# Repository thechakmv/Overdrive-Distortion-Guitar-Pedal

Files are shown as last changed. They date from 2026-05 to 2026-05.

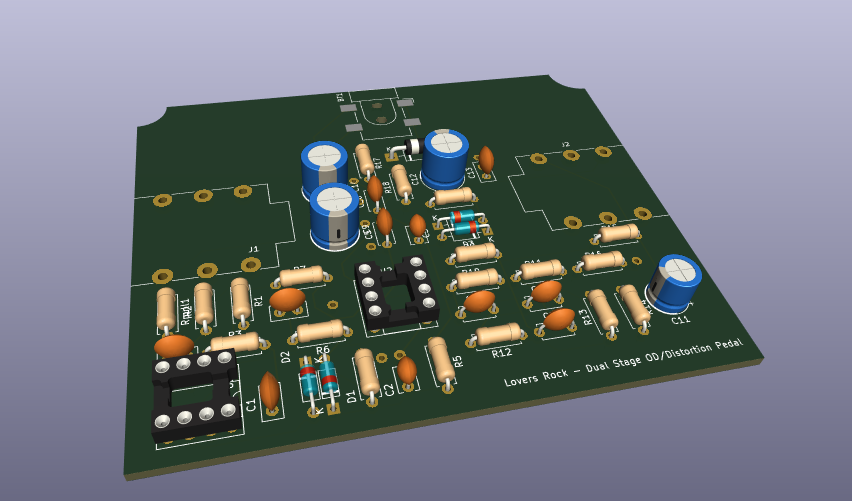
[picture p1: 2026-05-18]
images/pcb_3d.png

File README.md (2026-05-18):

# Dual-Stage Overdrive & Distortion Guitar Pedal

I created analog guitar effects pedal with two independent, switchable gain stages featuring deliberately opposite midrange voicings to achieve classic Thrash metal rhythm and lead tones: a soft-clipping overdrive with a **mid-boost** (+6 dB at 800 Hz) and a hard-clipping distortion with a **mid-scoop** (−6 to −10 dB across 400–800 Hz). The Pedal features a single-knob passive tone control, and volume control as well. Each stage has true-bypass switching, so the two can run independently or be cascaded for stacked high-gain tones.

## Highlights

- Designed and simulated in LTSpice; verified Bode plots, transient behavior, and FFT spectrum on hardware
- Two-stage analog signal chain built around TL072 JFET-input op-amps
- True-bypass per stage via 3PDT footswitches; both stages engage simultaneously for cascaded gain
- Passive Twin-T notch filter for the distortion mid-scoop voicing
- Single 9 V DC supply, ~30 mA total current draw
- PCB layout in KiCad with attention to signal integrity, star-ground topology, and inter-stage isolation

## Signal Flow

```
                                                         
 Guitar ─> Input ─┬─> OD Stage ──┬─> Distortion ──┬─> Tone ─> Volume ─> Output ─> Amp
          Buffer  │   (soft clip,│   (hard clip + │  (LPF)    (audio)   Buffer
          (TL072) │   mid-boost) │   Twin-T scoop)│
                  │              │                │
                  ▼              ▼                ▼
                SW1 3PDT        SW2 3PDT       Always
                true bypass     true bypass    in signal path
```

When both footswitches are engaged, the OD output feeds the distortion stage input, producing cascaded high-gain saturation. Each stage can also run alone for cleaner crunch or for chunkier rhythm tones.

## Design Specifications

| Parameter | Value |
|---|---|
| Supply | 9 V DC, center-negative, ~30 mA |
| Frequency response (clean path) | Flat ±0.5 dB across 20 Hz – 20 kHz |
| OD voicing | +6 dB peak at 800 Hz; corners at 720 Hz and ~6 kHz |
| OD gain range | 0 dB to +41 dB |
| OD clipping | Soft, symmetric, ±0.6 V (1N4148 anti-parallel in feedback) |
| Distortion voicing | −6 to −10 dB notch centered at ~700 Hz |
| Distortion gain range | +14 dB to +54 dB |
| Distortion clipping | Hard, symmetric, ±0.6 V (1N4148 to Vref) |

## Design Philosophy

Where most pedals use a single clipping topology, this design uses two intentionally distinct stages whose characters complement each other when cascaded.

The **overdrive stage** is a Tube Screamer-derived non-inverting topology with silicon diodes inside the feedback loop. The feedback RC network forms a band-pass response: lows roll off below 720 Hz and highs roll off above ~6 kHz at maximum gain. Inside the band the gradual diode conduction produces soft clipping that preserves the dry signal underneath the saturation, giving the characteristic transparent overdrive sound.

The **distortion stage** uses an inverting topology with diodes clamping the op-amp output directly to the Vref node. This produces hard, square-wave clipping rich in odd harmonics. The clipped signal then feeds a passive Twin-T notch filter centered near 700 Hz, carving out the boxy midrange while leaving low and high content intact — the classic scooped-mid metal voicing.

The two stages are independently switchable: OD alone for crunch, distortion alone for chunky rhythm work, or both stacked for full-saturation lead tones.

## Repository Structure

```
├── ltspice/
│   ├── od_stage.asc
│   ├── distortion_stage.asc
│   └── Overdrive_Distortion_Schematic.asc              
├── kicad/
│   ├── pedal.kicad_pro             Project file
│   ├── pedal.kicad_sch             Schematic
│   ├── pedal.kicad_pcb             Board layout
│   └── gerbers/                    Fabrication output (zipped Gerbers + drill)
└── images/
    ├── frequency_response.png      Measured Bode plots
    ├── pcb_schematic.png          Spectrum analyzer captures
    └── pcb_3d.png                  Oscilloscope captures
```

## Tools

**Software:** LTSpice, KiCad 7

**Test equipment:** oscilloscope (FFT capable), signal generator, multimeter, soldering iron

## Build Process

1. **Simulate.** Run AC and transient analyses in LTSpice for each stage. Verify gain curves, clipping shape, and Vref stability under load. Use `.step` to sweep gain pot values and see the response variation across the control range.

2. **Breadboard.** Build stage-by-stage with bench power. Validate against simulation results with scope and FFT. This is the stage to tune by ear — swap diodes (Si vs. LED vs. asymmetric), tweak the scoop center frequency, dial in the gain ranges.

3. **PCB.** Re-capture the validated schematic in KiCad, assign through-hole footprints, lay out the board with the panel-component headers anchored to enclosure positions. Generate Gerbers and fabricate via JLCPCB or OSH Park.

**In Progress:**
1. **Assemble.** Populate the PCB; wire off-board panel components (pots, footswitches, jacks); mount in enclosure.

2. **Verify.** Measure assembled pedal's frequency response and FFT; compare against simulation predictions.

## Testing & Verification

The hardware was validated against simulation using:

**Bode plots:** swept sine across 20 Hz – 20 kHz, output captured on oscilloscope, magnitude plotted in dB. Measured curve matches LTSpice AC analysis within ±2 dB across the band.

**FFT analysis:** 1 kHz sine input at each stage's clipping threshold, output FFT'd to verify harmonic content. The OD stage shows soft-clip characteristic harmonic roll-off; the distortion stage shows hard-clip odd-harmonic series with a clear notch at ~700 Hz after the Twin-T.

## Design Issues Encountered (and Fixed)

Three non-obvious problems came up during simulation and breadboarding that are worth documenting:

**Vref instability under heavy distortion.** The hard-clipping diodes were pumping asymmetric current pulses into the unbuffered Vref node, dragging it from 4.5 V down toward 1 V during sustained clipping. Fixed by adding a 1 kΩ series resistor between the distortion op-amp's output and the diode pair, limiting peak diode current and preserving Vref bias integrity.

**High-frequency oscillation at high gain.** The TL072 stages were prone to oscillation when driving capacitive loads (cable runs, coupling caps). Fixed by adding a 470 Ω series isolation resistor between each op-amp output and its capacitive load, with feedback taken before the resistor.

**Switch-engage pop.** Resolved by adding 1 MΩ pull-down resistors on both sides of every coupling cap that interfaces with a footswitch, ensuring no DC charge accumulates on the disconnected side of the cap during bypass.

## Skills Demonstrated

- Analog circuit design with op-amps (inverting, non-inverting, follower topologies)
- Frequency-response shaping via reactive feedback networks
- Soft-clipping vs. hard-clipping topology selection and harmonic analysis
- Single-supply audio biasing: Vref generation, AC coupling, bypass strategy
- Passive filter design (Twin-T notch with derivation of component ratios)
- SPICE simulation: AC sweep, transient analysis, FFT, parametric stepping
- PCB layout for analog audio: ground topology, decoupling, inter-stage isolation
- Hardware validation against simulation with scope and spectrum analyzer

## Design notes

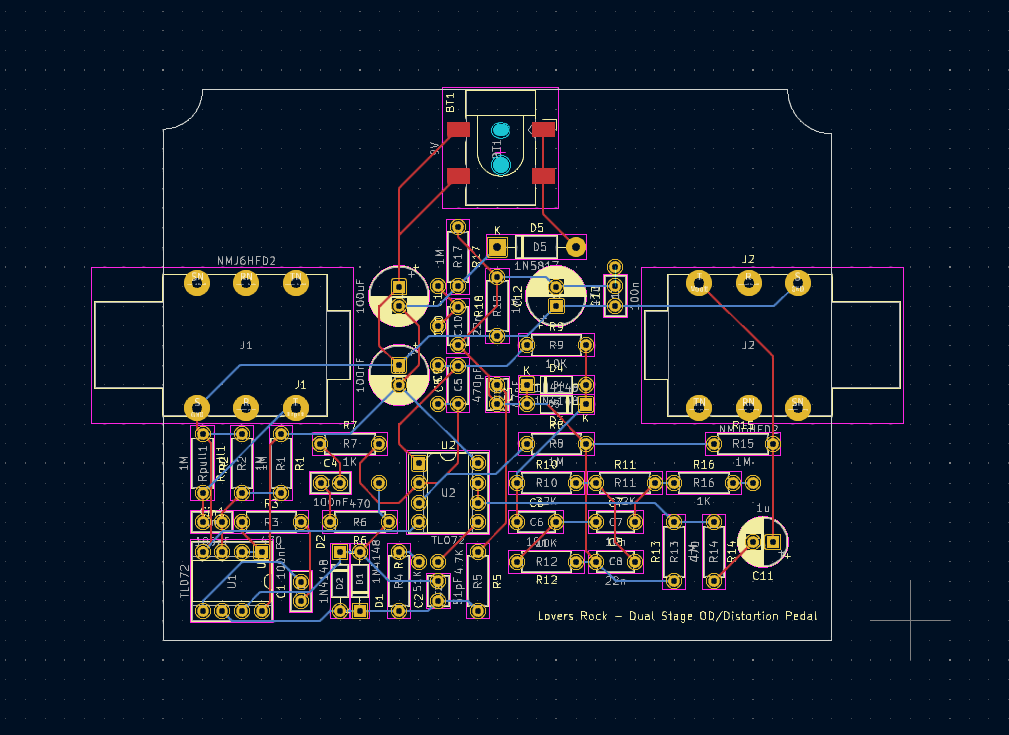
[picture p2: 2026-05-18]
images/pcb_schematic.png

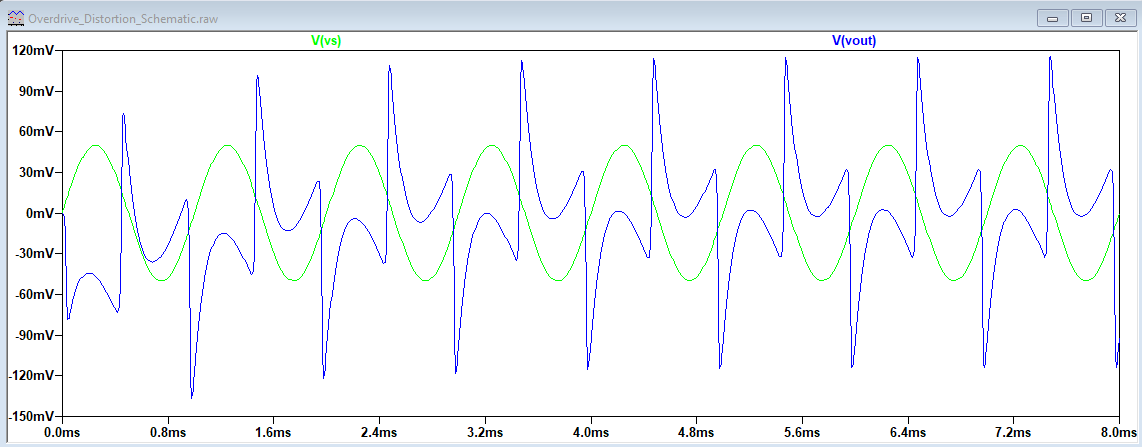
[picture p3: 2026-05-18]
images/transient.png

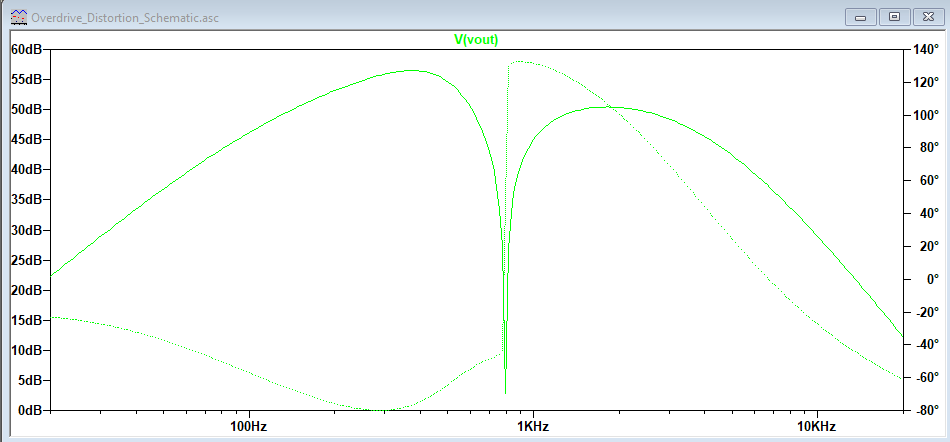
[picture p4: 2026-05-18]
images/frequency_response.png

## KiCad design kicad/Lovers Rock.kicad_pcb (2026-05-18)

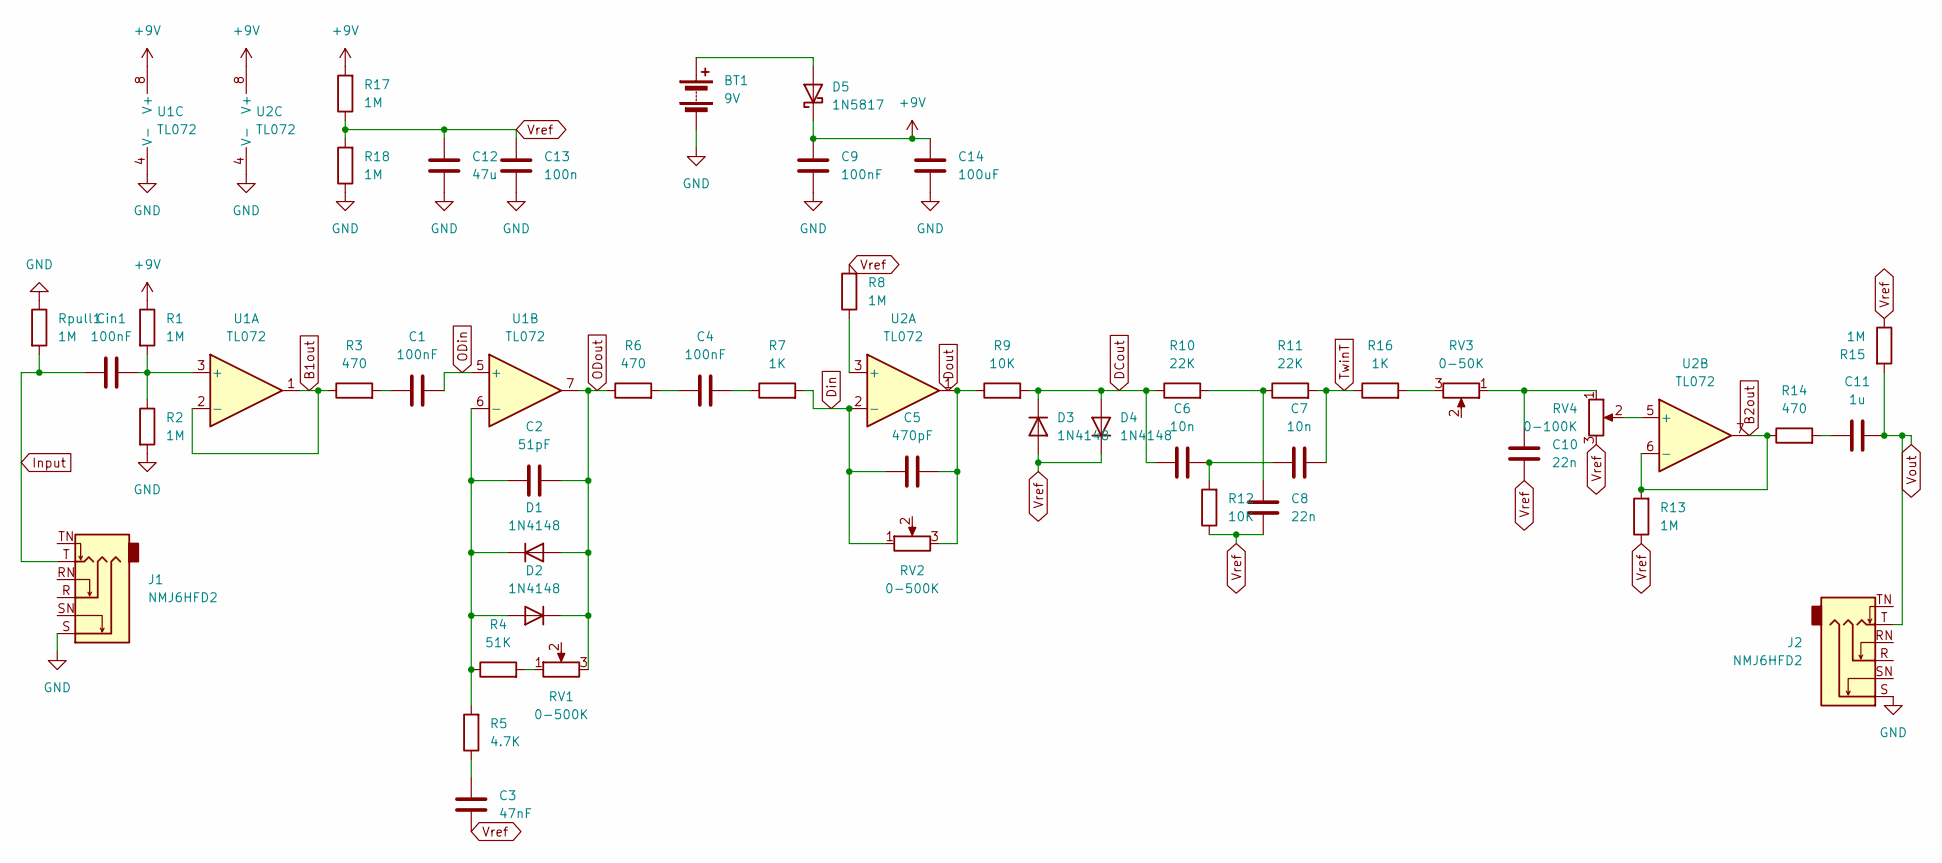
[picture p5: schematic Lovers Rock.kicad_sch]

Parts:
BT1: 9V; BarrelJack_CLIFF_FC681465S_SMT_Horizontal
C1, C4: 100nF; C_Disc_D5.0mm_W2.5mm_P2.50mm
C2: 51pF; C_Disc_D3.8mm_W2.6mm_P2.50mm
C3: 47nF; C_Disc_D3.8mm_W2.6mm_P2.50mm
C5: 470pF; C_Disc_D4.7mm_W2.5mm_P5.00mm
C6, C7: 10n; C_Disc_D4.7mm_W2.5mm_P5.00mm
C8, C10: 22n; C_Disc_D4.7mm_W2.5mm_P5.00mm
C9: 100nF; CP_Radial_D7.5mm_P2.50mm
C11: 1u; CP_Radial_D6.3mm_P2.50mm
C12: 47u; CP_Radial_D7.5mm_P2.50mm
C13: 100n; C_Disc_D5.0mm_W2.5mm_P2.50mm
C14: 100uF; CP_Radial_D7.5mm_P2.50mm
Cin1: 100nF; C_Disc_D5.0mm_W2.5mm_P2.50mm
D1, D2, D3, D4: 1N4148; D_DO-35_SOD27_P7.62mm_Horizontal
D5: 1N5817; D_DO-41_SOD81_P10.16mm_Horizontal
J1, J2: NMJ6HFD2; Jack_6.35mm_Neutrik_NMJ6HFD2_Horizontal
R1, R2, R8, R13, R15, R17, R18: 1M; R_Axial_DIN0207_L6.3mm_D2.5mm_P7.62mm_Horizontal
R3, R6, R14: 470; R_Axial_DIN0207_L6.3mm_D2.5mm_P7.62mm_Horizontal
R4: 51K; R_Axial_DIN0207_L6.3mm_D2.5mm_P7.62mm_Horizontal
R5: 4.7K; R_Axial_DIN0207_L6.3mm_D2.5mm_P7.62mm_Horizontal
R7, R16: 1K; R_Axial_DIN0207_L6.3mm_D2.5mm_P7.62mm_Horizontal
R9, R12: 10K; R_Axial_DIN0207_L6.3mm_D2.5mm_P7.62mm_Horizontal
R10, R11: 22K; R_Axial_DIN0207_L6.3mm_D2.5mm_P7.62mm_Horizontal
RV1, RV2: 0-500K; Potentiometer_Bourns_PTV09A-1_Single_Vertical
RV3: 0-50K; Potentiometer_Bourns_PTV09A-1_Single_Vertical
RV4: 0-100K; Potentiometer_Bourns_PTV09A-1_Single_Vertical
Rpull1: 1M; R_Axial_DIN0207_L6.3mm_D2.5mm_P7.62mm_Horizontal
U1, U2: TL072; DIP-8_W7.62mm_Socket

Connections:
+9V: C9.2, C14.2, D5.1 (K), R1.1, R17.2, U1.8 (V+), U2.8 (V+)
B1out: R3.1, U1.1, U1.2 (-)
B2out: R13.2, R14.1, U2.6 (-), U2.7
DCout: C6.1, D3.1 (K), D4.2 (A), R9.2, R10.1
Din: C5.1, R7.2, RV2.1, U2.2 (-)
GND: BT1.2 (-), C9.1, C12.1, C13.1, C14.1, J1.S, J2.S, R2.2, R18.1, Rpull1.1, U1.4 (V-), U2.4 (V-)
Input: Cin1.1, J1.T, Rpull1.2
unnamed: BT1.1 (+), D5.2 (A)
unnamed: C1.1, R3.2
unnamed: C3.2, R5.1
unnamed: C4.1, R6.2
unnamed: C4.2, R7.1
unnamed: C5.2, R9.1, RV2.3, U2.1
unnamed: C6.2, C7.1, R12.2
unnamed: C8.2, R10.2, R11.1
unnamed: C10.2, RV3.1, RV4.1
unnamed: C11.2, R14.2
unnamed: C2.1, D1.1 (K), D2.2 (A), R4.1, R5.2, U1.6 (-)
unnamed: R4.2, RV1.1
unnamed: R16.2, RV3.3
unnamed: Cin1.2, R1.2, R2.1, U1.3 (+)
unnamed: R8.1, U2.3 (+)
unnamed: RV4.2, U2.5 (+)
ODin: C1.2, U1.5 (+)
ODout: C2.2, D1.2 (A), D2.1 (K), R6.1, RV1.3, U1.7
TwinT: C7.2, R11.2, R16.1
Vout: C11.1, J2.T, R15.2
Vref: C3.1, C8.1, C10.1, C12.2, C13.2, D3.2 (A), D4.1 (K), R8.2, R12.1, R13.1, R15.1, R17.1, R18.2, RV4.3

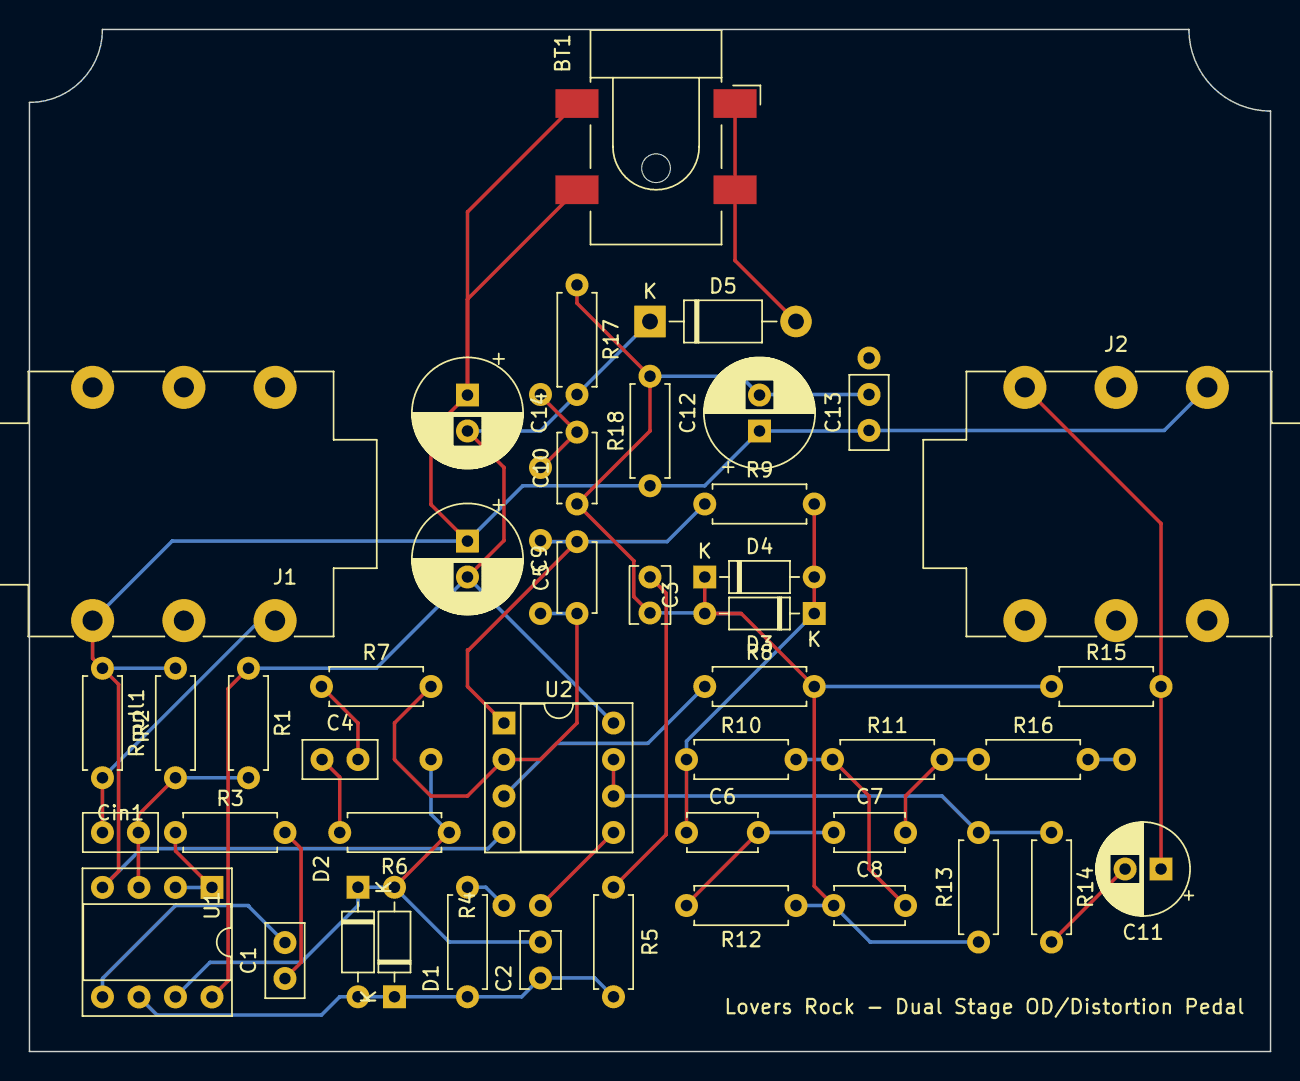
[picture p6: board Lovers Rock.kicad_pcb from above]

Board: 2 copper layers, 86.4 x 71.1 mm, 44 parts (0 on the bottom side), 24 nets.
